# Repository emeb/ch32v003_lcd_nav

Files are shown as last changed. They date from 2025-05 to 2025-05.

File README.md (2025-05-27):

# ch32v003_lcd_nav
A simple CH32V003 board with IPS LCD and navigation switch.

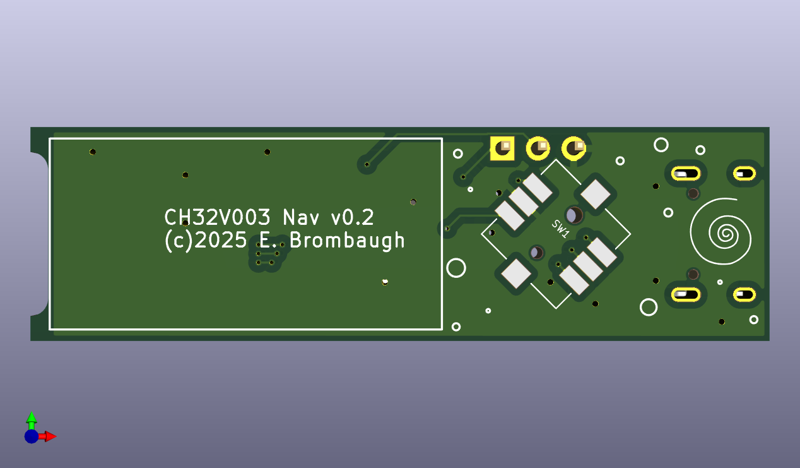
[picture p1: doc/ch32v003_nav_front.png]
front render

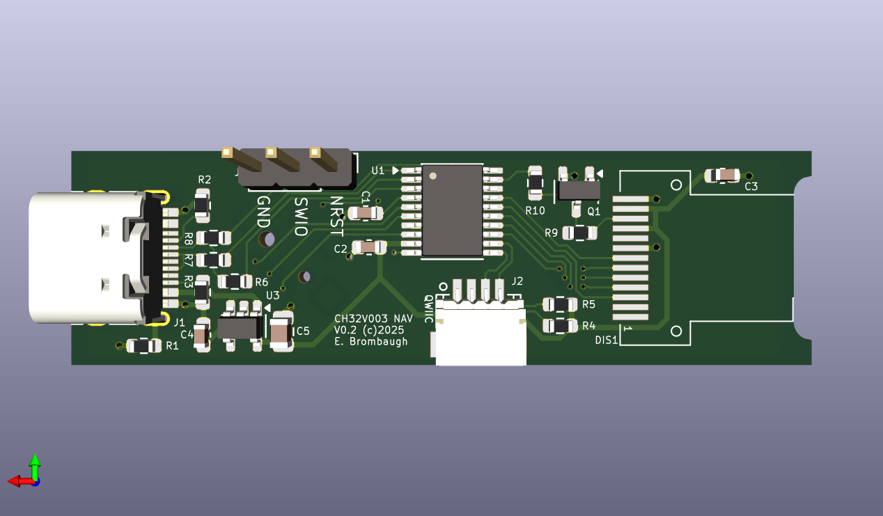
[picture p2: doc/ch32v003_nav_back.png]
back render

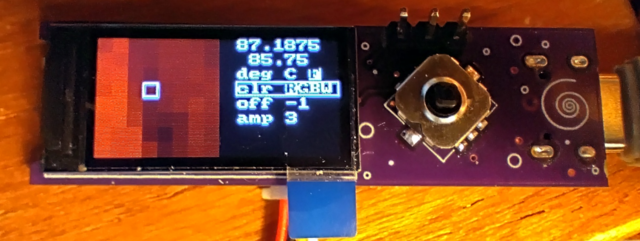
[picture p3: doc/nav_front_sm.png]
front image

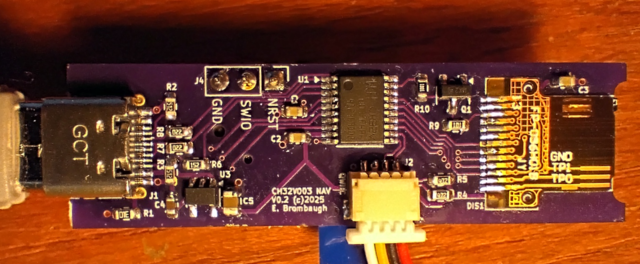
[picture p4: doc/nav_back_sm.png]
back image


## Abstract
This is a board with the following features:
* CH32V003F4P6 RISC-V MCU in TSSOP20 package
* 160x80 IPS LCD display
* 5-way navigation switch
* USB socket with power and optional low-speed interface
* Qwiic jack for I2C interfacing

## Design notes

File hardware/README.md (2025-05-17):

# Hardware Design
This directory contains the KiCad 8.09 design files for the ch32v003_nav board
design.

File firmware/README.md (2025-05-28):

# Firmware
This directory contains various firmware resources for the CH32V003 LCD NAV board.
It relies on CNLohr's CH32Fun build system and you'll need to initialize it with
the following commands:

```
git submodule init
git submodule update
```
which will pull in the required repository. Then just drop down into the projects
you're interested in and build them:
```
cd nl_irscope
make
```

## USB
In order to use the USB functionality you'll need to build code in the
rv003usb repo. I have a fork + branch of this with demo code showing how to
use the 5-way nav switch as a HID gamepad. Look for it here:

[rv003usb repo](https://github.com/emeb/rv003usb/tree/bubble/nl_gamepad)

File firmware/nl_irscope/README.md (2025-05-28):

# nl_irscope
This directory contains source for a simple graphic driver for the AMG8833
8x8 infrared detector. It uses the 5-way nav switch to select various display
options, including

* Choice of readout in deg C or F
* Choice of Red/Green/Blue/White color rendering
* Setting the low-end temperature offset
* Setting the gain of the temperature to color mapping

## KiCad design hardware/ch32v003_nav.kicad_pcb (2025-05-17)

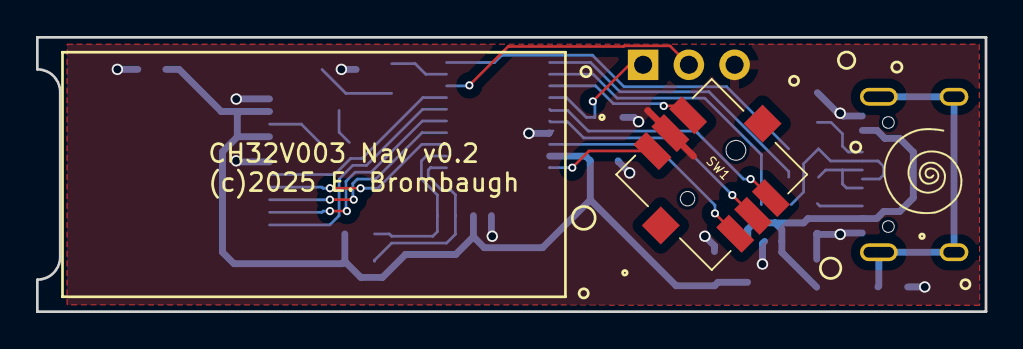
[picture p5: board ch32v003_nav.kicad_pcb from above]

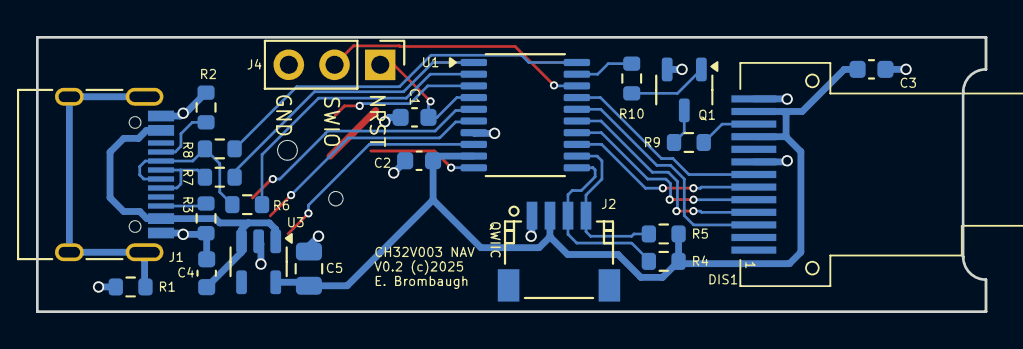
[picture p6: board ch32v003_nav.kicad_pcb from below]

Board: 2 copper layers, 52.7 x 15.2 mm, 24 parts (22 on the bottom side), 29 nets.

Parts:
C1, C2, C3: 0.1uf; C_0603_1608Metric
C4: 1uf; C_0603_1608Metric
C5: 10uf; C_0805_2012Metric
DIS1: 0.96_IPS_TFT_LCD
J1: USB_C_Receptacle_USB2.0; USB_C_Receptacle_HRO_TYPE-C-31-M-12
J2: JST SH-4 (Qwiic); JST_SH_SM04B-SRSS-TB_04x1.00mm_Angled
J4: Conn_01x03_Pin; PinHeader_1x03_P2.54mm_Vertical
Q1: DMN63D8L; SOT-23-3
R1: 1M; R_0603_1608Metric
R2, R3: 5k1; R_0603_1608Metric
R4, R5: 4k7; R_0603_1608Metric
R6: 1.5k; R_0603_1608Metric
R7, R8: 22; R_0603_1608Metric
R9: 100; R_0603_1608Metric
R10: 1k; R_0603_1608Metric
Ref**: Val**; avatar_small
SW1: nav_5way
U1: CH32V003F4P6; TSSOP-20_4.4x6.5mm_P0.65mm
U3: XC6222B331MR-G; SOT-23-5

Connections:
+3.3V: C2.1, C3.1, C5.1, DIS1.10 (VCC), DIS1.12 (LEDA), J2.2, R4.2, R5.2, U1.9 (VDD), U3.5 (VOUT)
/JS_CTR: SW1.5 (CTR), U1.6 (PA2)
/JS_NE: SW1.6 (NE), U1.5 (PA1)
/JS_NW: SW1.1 (NW), U1.3 (PD6)
/JS_SE: SW1.4 (SE), U1.8 (PD0)
/JS_SW: SW1.3 (SW), U1.10 (PC0)
/LCD_BKL: R10.2, U1.19 (PD2)
/LCD_CS: DIS1.7 (CS), U1.17 (PC7)
/LCD_D/C: DIS1.5 (RS), U1.14 (PC4)
/LCD_MOSI: DIS1.3 (SDA), U1.16 (PC6)
/LCD_NRST: DIS1.6 (RES), U1.13 (PC3)
/LCD_SCLK: DIS1.4 (SCL), U1.15 (PC5)
/NRST: C1.1, J4.1, U1.4 (PD7)
/SCL: J2.4, R5.1, U1.12 (PC2)
/SDA: J2.3, R4.1, U1.11 (PC1)
/SWIO: J4.2, U1.18 (PD1)
/USB_DM: R8.1, U1.20 (PD3)
/USB_DP: R7.1, U1.1 (PD4)
/USB_DPU: R6.1, U1.2 (PD5)
/VUSB: C4.1, J1.A4 (VBUS), J1.A9 (VBUS), J1.B4 (VBUS), J1.B9 (VBUS), U3.1 (VIN), U3.3 (CE)
GND: C1.2, C2.2, C3.2, C4.2, C5.2, DIS1.8 (GND), DIS1.13 (GND), J1.A1 (GND), J1.A12 (GND), J1.B1 (GND), J1.B12 (GND), J2.1, J4.3, Q1.2 (S), R1.1, R2.1, R3.1, SW1.2 (COM), U1.7 (VSS), U3.2 (GND)
unnamed: DIS1.11 (LEDK), R9.2
unnamed: J1.A5 (CC1), R2.2
unnamed: J1.B5 (CC2), R3.2
unnamed: J1.A6 (D+), J1.B6 (D+), R7.2
unnamed: J1.A7 (D-), J1.B7 (D-), R6.2, R8.2
unnamed: J1.S1 (SHIELD), R1.2
unnamed: Q1.3 (D), R9.1
unnamed: Q1.1 (G), R10.1

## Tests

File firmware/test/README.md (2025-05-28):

# Test
This directory contains source for a test of the LCD and nav switch. When run
it draws dots of random colors at random locations with the word "Hi" in them.
If the nav switch is used then arrows are drawn on the screen in a diamond
pattern matching the locations pressed.

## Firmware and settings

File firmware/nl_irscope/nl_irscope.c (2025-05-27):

/*
 * nav button & LCD
 * 04-29-2025 E. Brombaugh
 */
 
/*
 * Pin assignments for 20-pin package
 * Pin # | GPIO     | Signal   | Function
 *  1      PD4        USB_DP     USB Data +
 *  2      PD5        USB_DPU    USB pullup
 *  3      PD6    	  JS_NW      Joystick NW switch
 *  4      PD7    	  NRST       Low-true reset
 *  5      PA1        JS_NE		 Joystick NE switch
 *  6      PA2   	  JS_CTR	 Joystick Center switch
 *  7      VSS        GND		 Power
 *  8      PD0        JS_SE      Joystick SE switch
 *  9      VDD        +3.3V      Power
 *  10     PC0        JS_SW      Joystick SW switch
 *  11     PC1        SDA        I2C data / piezo
 *  12     PC2        SCL        I2C clock / piezo 
 *  13     PC3        LCD_NRST   Display low-rtue reset
 *  14     PC4        LCD_D/C    Display cmd/data 
 *  15     PC5        LCD_SCLK   Display serial clock
 *  16     PC6        LCD_MOSI   Display serial data
 *  17     PC7        LCD_CS     Display select 
 *  18     PD1        SWIO       Programmer 
 *  19     PD2        LCD_BKL    Display backlight 
 *  20     PD3        USB_DM     USB Data - 
 */

/* uncomment this to try pwm hue */
#define HUE

#include "ch32fun.h"
#include <stdio.h>
#include <string.h>
#include "systick.h"
#include "gfx.h"
#include "lcd.h"
#include "amg8833.h"
#include "menu.h"

/* build version in simple format */
const char *fwVersionStr = "V1.0";

/* build time */
const char *bdate = __DATE__;
const char *btime = __TIME__;

/*
 * convert Thermistor to int/frac in C or F
 */
void therm2if(uint16_t therm, uint8_t *c_int, uint16_t *c_frac, uint8_t f)
{
	if(f)
	{
		/* convert to fahrenheit: 1843/1024 + (32*16) */
		uint32_t temp = ((1843*(uint32_t)therm) >> 10) + (32<<4);
		therm = temp;
	}
	*c_frac = (therm&0xf) * 625;
	*c_int = (therm>>4);
}

/*
 * convert IR element to int/frac in C or F
 */
void ir2if(uint16_t ir, uint8_t *c_int, uint8_t *c_frac, uint8_t f)
{
	if(f)
	{
		/* convert to fahrenheit: 1843/1024 + (32*4) */
		uint32_t temp = ((1843*(uint32_t)ir) >> 10) + (32<<2);
		ir = temp;
	}
	*c_frac = (ir&3) * 25;
	*c_int = (ir>>2);
}

/*
 * convert byte to RGB color
 */
GFX_COLOR color_map(uint8_t scale, uint8_t map)
{
	GFX_COLOR result;
	
	switch(map)
	{
		case 0: /* Red */
			result = scale << 16;
			break;
		
		case 1: /* Green */
			result = scale << 8;
			break;
		
		case 2: /* Blue */
			result = scale;
			break;
		
		case 3: /* White */
		default:
			result = (scale << 16) | (scale << 8) | scale ;\
			break;
	}
	return result;
}

/*
 * Start here
 */
int main()
{
	// setup basic stuff - clocks, serial, etc
	SystemInit();

	// start serial @ default 115200bps
	Delay_Ms( 100 );
	printf("\r\r\n\nNL IRScope\n\r");
	printf("Version: %s\n\r", fwVersionStr);
	printf("Build Date: %s\n\r", bdate);
	printf("Build Time: %s\n\r", btime);
	
	/* init systick */
	systick_init();
	printf("initialized systick IRQ\n\r");
	
	/* init lcd */
	gfx_init(&ST7735_drvr);
	gfx_clrscreen();
	lcd_bkl(1);
	printf("initialized graphics & LCD\n\r");
	
	/* init am8833 IR sensor */
	gfx_set_forecolor(GFX_WHITE);
	gfx_drawstrctr(80, 40-4, "Initializing Sensor");
	Delay_Ms(100);
	if(amg8833_init())
	{
		gfx_set_forecolor(GFX_RED);
		gfx_drawstrctr(80, 40-4, "  IR Sensor failed  ");
		printf("IR sensor init failed... halting.\n\r");
		while(1) {}
	}
	else
	{	gfx_clrscreen();
		printf("initialized IR sensor\n\r");
	}

	/* start menu */
	menu_init();
	printf("initialized menu\n\r");

	printf("Looping...\n\r");
	while(1)
	{
		// readout built-in thermistor
		uint16_t temp, tf;
		uint8_t ti;
		amg8833_get_thermistor(&temp);
		therm2if(temp, &ti, &tf, menu_item_vals[0]);
		//printf("Thermistor: %d.%04d\n\r", ti, tf);
		sprintf(textbuf, "%d.%04d", ti, tf);
		gfx_set_forecolor(GFX_WHITE);
		gfx_drawstr(MNU_XSTART, 0, textbuf);
		
		// get array
		uint16_t ir_array[64];
		uint8_t ci, cf;
		amg8833_get_array(ir_array);
		
		// readout center element
		ir2if(ir_array[3*8+3], &ci, &cf, menu_item_vals[0]);
		sprintf(textbuf, "%3d.%02d", ci, cf);
		gfx_drawstr(MNU_XSTART, MNU_YSPACE, textbuf);
		
		// render 8x8 array grid
		GFX_RECT rect;
		for(int y = 0;y<8;y++)
		{
			/* render graphics */
			for(int x = 0;x<8;x++)
			{
				int16_t scale = ((int16_t)ir_array[y*8+x]-110 + menu_item_vals[2])<<menu_item_vals[3];
				scale = scale < 0 ? 0 : scale;
				scale = scale > 255 ? 255 : scale;
				rect.x0 = x*10;
				rect.y0 = y*10;
				rect.x1 = rect.x0+9;
				rect.y1 = rect.y0+9;
				gfx_colorrect(&rect, color_map(scale, menu_item_vals[1]));
				
				// draw a box around center rect
				if((x==3)&&(y==3))
					gfx_drawrect(&rect);

			}
		}
		
		/* handle menu */
		menu_proc();
		
		Delay_Ms(100);
	}
}

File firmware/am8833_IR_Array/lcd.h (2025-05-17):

/*
 * lcd.h - single-file header for RGB LED
 * 09-28-24 E. Brombaugh
 */

/*
 * Pin assignments for LCD on 20-pin package
 * Pin # | GPIO     | Signal   | Function
 *  13     PC3        LCD_NRST   Display low-rtue reset
 *  14     PC4        LCD_D/C    Display cmd/data 
 *  15     PC5        LCD_SCLK   Display serial clock
 *  16     PC6        LCD_MOSI   Display serial data
 *  17     PC7        LCD_CS     Display select 
 *  19     PD2        LCD_BKL    Display backlight 
 */

#ifndef __lcd__
#define __lcd__

#define LCD_NRST_PORT GPIOC
#define LCD_NRST_PIN 3
#define LCD_NRST_HIGH() LCD_NRST_PORT->BSHR = (1<<(LCD_NRST_PIN))
#define LCD_NRST_LOW() LCD_NRST_PORT->BSHR = (1<<(16+LCD_NRST_PIN))
#define LCD_DC_PORT GPIOC
#define LCD_DC_PIN 4
#define LCD_DC_DATA() LCD_DC_PORT->BSHR = (1<<(LCD_DC_PIN))
#define LCD_DC_CMD() LCD_DC_PORT->BSHR = (1<<(16+LCD_DC_PIN))
#define LCD_SCLK_PORT GPIOC
#define LCD_SCLK_PIN 5
#define LCD_MOSI_PORT GPIOC
#define LCD_MOSI_PIN 6
#define LCD_CS_PORT GPIOC
#define LCD_CS_PIN 7
#define LCD_CS_HIGH() LCD_CS_PORT->BSHR = (1<<(LCD_CS_PIN))
#define LCD_CS_LOW() LCD_CS_PORT->BSHR = (1<<(16+LCD_CS_PIN))
#define LCD_BKL_PORT GPIOD
#define LCD_BKL_PIN 2
#define LCD_BKL_HIGH() LCD_BKL_PORT->BSHR = (1<<(LCD_BKL_PIN))
#define LCD_BKL_LOW() LCD_BKL_PORT->BSHR = (1<<(16+LCD_BKL_PIN))

#define ST7735_TFTWIDTH 80
#define ST7735_TFTHEIGHT 160

#define ST_CMD            0x100
#define ST_CMD_DELAY      0x200
#define ST_CMD_END        0x400

#define ST77XX_NOP        0x00
#define ST77XX_SWRESET    0x01
#define ST77XX_RDDID      0x04
#define ST77XX_RDDST      0x09

#define ST77XX_SLPIN      0x10
#define ST77XX_SLPOUT     0x11
#define ST77XX_PTLON      0x12
#define ST77XX_NORON      0x13

#define ST77XX_INVOFF     0x20
#define ST77XX_INVON      0x21
#define ST77XX_DISPOFF    0x28
#define ST77XX_DISPON     0x29
#define ST77XX_CASET      0x2A
#define ST77XX_RASET      0x2B
#define ST77XX_RAMWR      0x2C
#define ST77XX_RAMRD      0x2E

#define ST77XX_PTLAR      0x30
#define ST77XX_COLMOD     0x3A
#define ST77XX_MADCTL     0x36

#define ST77XX_MADCTL_MY  0x80
#define ST77XX_MADCTL_MX  0x40
#define ST77XX_MADCTL_MV  0x20
#define ST77XX_MADCTL_ML  0x10
#define ST77XX_MADCTL_RGB 0x08
#define ST77XX_MADCTL_MH  0x04


#define ST77XX_RDID1      0xDA
#define ST77XX_RDID2      0xDB
#define ST77XX_RDID3      0xDC
#define ST77XX_RDID4      0xDD

#define ST7735_SCRLAR     0x33
#define ST7735_VSCSAD     0x37

#define ST7735_FRMCTR1    0xB1
#define ST7735_FRMCTR2    0xB2
#define ST7735_FRMCTR3    0xB3
#define ST7735_INVCTR     0xB4
#define ST7735_DISSET5    0xB6

#define ST7735_PWCTR1     0xC0
#define ST7735_PWCTR2     0xC1
#define ST7735_PWCTR3     0xC2
#define ST7735_PWCTR4     0xC3
#define ST7735_PWCTR5     0xC4
#define ST7735_VMCTR1     0xC5

#define ST7735_GMCTRP1    0xE0
#define ST7735_GMCTRN1    0xE1

#define ST7735_PWCTR6     0xFC

/* ----------------------- private variables ----------------------- */
// Initialization command sequence
const static uint16_t
  initlst[] = {
    // mini is ST7735R
    // 7735R init, part 1 (red or green tab)
                                    // 15 commands in list:
    ST77XX_SWRESET | ST_CMD,        //  1: Software reset, 0 args, w/delay
    ST_CMD_DELAY | 15,             //     150 ms delay
    ST77XX_SLPOUT | ST_CMD,         //  2: Out of sleep mode, 0 args, w/delay
    ST_CMD_DELAY | 50,             //     500 ms delay
    ST7735_FRMCTR1 | ST_CMD,        //  3: Framerate ctrl - normal mode, 3 arg:
      0x01, 0x2C, 0x2D,             //     Rate = fosc/(1x2+40) * (LINE+2C+2D)
    ST7735_FRMCTR2 | ST_CMD,        //  4: Framerate ctrl - idle mode, 3 args:
      0x01, 0x2C, 0x2D,             //     Rate = fosc/(1x2+40) * (LINE+2C+2D)
    ST7735_FRMCTR3 | ST_CMD,        //  5: Framerate - partial mode, 6 args:
      0x01, 0x2C, 0x2D,             //     Dot inversion mode
      0x01, 0x2C, 0x2D,             //     Line inversion mode
    ST7735_INVCTR | ST_CMD,         //  6: Display inversion ctrl, 1 arg:
      0x07,                         //     No inversion
    ST7735_PWCTR1 | ST_CMD,         //  7: Power control, 3 args, no delay:
      0xA2,
      0x02,                         //     -4.6V
      0x84,                         //     AUTO mode
    ST7735_PWCTR2 | ST_CMD,         //  8: Power control, 1 arg, no delay:
      0xC5,                         //     VGH25=2.4C VGSEL=-10 VGH=3 * AVDD
    ST7735_PWCTR3 | ST_CMD,         //  9: Power control, 2 args, no delay:
      0x0A,                         //     Opamp current small
      0x00,                         //     Boost frequency
    ST7735_PWCTR4 | ST_CMD,         // 10: Power control, 2 args, no delay:
      0x8A,                         //     BCLK/2,
      0x2A,                         //     opamp current small & medium low
    ST7735_PWCTR5 | ST_CMD,         // 11: Power control, 2 args, no delay:
      0x8A, 0xEE,
    ST7735_VMCTR1 | ST_CMD,         // 12: Power control, 1 arg, no delay:
      0x0E,
    ST77XX_INVOFF | ST_CMD,         // 13: Don't invert display, no args
    ST77XX_MADCTL | ST_CMD,         // 14: Mem access ctl (directions), 1 arg:
      0xC8,                         //     row/col addr, bottom-top refresh
    ST77XX_COLMOD | ST_CMD,         // 15: set color mode, 1 arg, no delay:
      0x05,                         //     16-bit color#endif

                                    // 7735R init, part 2 (mini 160x128)
                                    //  2 commands in list:
    ST77XX_CASET | ST_CMD,          //  1: Column addr set, 4 args, no delay:
      0x00, 0x00,                   //     XSTART = 0
      0x00, 0x7F,                   //     XEND = 127
    ST77XX_RASET | ST_CMD,          //  2: Row addr set, 4 args, no delay:
      0x00, 0x00,                   //     XSTART = 0
      0x00, 0x9F,                   //     XEND = 159

                                    // 7735R init, part 3 (red or green tab)
                                    //  4 commands in list:
    ST7735_GMCTRP1 | ST_CMD,        //  1: Gamma Adjustments (pos. polarity), 16 args + delay:
      0x02, 0x1c, 0x07, 0x12,       //     (Not entirely necessary, but provides
      0x37, 0x32, 0x29, 0x2d,       //      accurate colors)
      0x29, 0x25, 0x2B, 0x39,
      0x00, 0x01, 0x03, 0x10,
    ST7735_GMCTRN1 | ST_CMD,        //  2: Gamma Adjustments (neg. polarity), 16 args + delay:
      0x03, 0x1d, 0x07, 0x06,       //     (Not entirely necessary, but provides
      0x2E, 0x2C, 0x29, 0x2D,       //      accurate colors)
      0x2E, 0x2E, 0x37, 0x3F,
      0x00, 0x00, 0x02, 0x10,
    ST77XX_NORON | ST_CMD,          //  3: Normal display on, no args, w/delay
    ST_CMD_DELAY | 10,              //     10 ms delay
    ST77XX_DISPON | ST_CMD,         //  4: Main screen turn on, no args w/delay
    ST_CMD_DELAY | 10,             //     100 ms delay
	ST_CMD_END                      //  END OF LIST
};

/* LCD state */
uint8_t rowstart, colstart;
uint16_t _width, _height, rotation;
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

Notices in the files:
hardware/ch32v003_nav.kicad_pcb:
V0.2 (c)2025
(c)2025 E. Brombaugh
